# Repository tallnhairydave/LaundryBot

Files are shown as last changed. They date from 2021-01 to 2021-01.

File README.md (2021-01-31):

# LaundryBot
ESP8266 based CT Clamp sensor for monitoring washing machine power usage and reporting into HomeAssistant. Includes an OLED display for visible information in the kitchen, and is housed in a 3D printed enclosure. 

1. You need ESPHome add-on installed and running in HomeAssistant. 
1. You will need the fonts listed in fonts/readme.txt downloaded and installed in your HA installation in config/esphome/fonts/
1. Create a new ESPHome node
1. Update the laundrybot.yaml to suit your OTA and API passwords set during creation of the new node, and your WIFI network settings.
1. Compile and upload the code to your D1 Mini via serial for the first time from ESPHome. Future updates can then be OTA.
1. Add the code in the configuration.yaml file here on Github to your configuration.yaml - this will create the switch to turn on and off the display on the Laundrybot.
1. Check your configuration.yaml is valid, then restart HA.
1. Create a new entities card on your lovelace dashboard for Laundrybot. See lovelacecardcode.txt for my code for a basic status card. You can of course use Sensor cards if you want a nice graph of A or W usage over time for your washing machine.

Once you've got the data coming into HA, you can then fire off notifications etc depending on the washing machine state. :)

You'll also need a 3D printer to print out the enclosure :) I've included the STL's to print out my housing for the circuit board that holds the Wemos D1 mini, the display, and the circuit to connect to the CT Clamp.

**THIS IS DESIGNED AND BUILT TO WORK WITH A UK SINGLE PHASE 240V 3 CORE MAINS POWER CABLE, the CT Clamp goes around the LIVE core of the wire inside a junction box.**

I am using it to monitor my washing machine, so I've made an "extension lead" by cutting a 1 gang 5M extension cable in half, exposing the three cores and re-terminating them inside a junction box with screw down cable glands for cable entry. That way, the mains cable is safe and the CT clamp can be placed around the LIVE wire to enable current to be monitored. The washing machine then plugs into that "extension lead" instead of directly into the wall, and it goes without saying that **the extension lead has the same rating fuse installed in it's plug as the washing machine has in it's plug.**

Note, I've found that after laundrybot boots, it takes a few seconds once it's started sending data into HA before it "settles down" and stops reporting spurious current readings. 

**I AM IN NO WAY RESPONSIBLE FOR ANY ISSUES THAT MAY ARISE IF YOU BUILD THIS CIRCUIT AND WIRE UP ANYTHING TO IT. PROCEED AT YOUR OWN RISK**

## BILL OF MATERIALS:
* 1 x Wemos D1 Mini ESP8266 
* 1 x 1.3inch I2C Serial 128x64 SSH1106 OLED LCD Display  
* 1 x 4 pin female header for solderable protoboard for the display
* 2 x 8 pin female header for solderable protoboard for the D1 Mini (my board came with these)
* 2 x 8 pin male headers for the D1 mini (my board came with these and I just had to solder them on)
* 1 x SCT-013-030, 30A 0-1V output CT Clamp, e.g. https://www.amazon.co.uk/gp/product/B07MY361ZW - Important note, your CT clamp MUST have an inbuilt "burden resistor" as my circuit used (see the fritzing diagram) does include one, as the CT Clamp I used has a burden resistor built in. When I cut off the 3.5mm headphone jack from my CT Clamp, I found it had one red core and one black core. I connected these to the 2 wire terminal block as shown in the fritzing diagram. Make sure that you clamp it on the LIVE core inside the junction box with the ARROWS on the CT Clamp matching the direction of current flow. **NEVER ALLOW THE CT CLAMP TO OPERATE "OPEN CIRCUIT" i.e. do not connect it around the live wire and turn on the power, UNLESS the wires from the CT Clamp are connected to the terminals on the circuit board**
* 1 x Electrocookie 1/2 size solderable breadboard, or Adafruit 1/2 size protoboard. Both will fit in the case as they have the same 3mm fixing holes.
* 1 x 90 degree micro USB cable (if you want the power for the D1 mini to exit downwards from the case)
* 2 x M3x6 (no longer than M3x8) machine screws to hold the protoboard in the case
* 1 x 10µF Capacitor
* 2 x 10k Resistors - according to this guide at https://savjee.be/2019/07/Home-Energy-Monitor-ESP32-CT-Sensor-Emonlib/ (Thanks dude, your article on how to wire up the CT Clamp was invaluable!) any resistors between 10K and 470K are suitable, as long as they are both the same value.
* 1 x 2 wires screw terminal for solderable protoboard (note that the terminal block I used occupies 3 pins width on the board, with an unused column between it's two pins, see the fritzing diagram)
* 2 x M2.5x8 machine screws to hold the display to it's printed support. I designed the support to have M3 screw holes, but they printed too small so had to use M2.5 screws instead. YMMV
* A length of CAT6 network cable to run from the laundrybot location to the location of your power enclosure to house the CT Clamp. I used CAT6 as I had some lying around. CAT5e will work fine.  You could simply cut the ends off of a suitable length ethernet cable and use that instead of using spare cable from a spool like I did. 
* A small piece of 1mm thick foam tape (e.g. 3M VHB) to stick the base of the screen support piece to the protoboard if desired.
* Assorted 22 AWG wires to make jumpers for the solderable protoboard
* Assorted heatshrink tube (a) to tidy the wiring loom for the display, (b) to insulate the soldered joint between the CT Clamp to two pairs of the CAT6 cable used to extend the wiring, and (c) as needed for the mains cable, depending on how you terminate it inside the junction box.
* 1 x zip tie to act as strain relief on the CAT6 cable where it enters the Laundrybot housing in case it somehow gets tugged. You can also hot-glue it down to the protoboard. 
* 1 x ABS junction box at large enough to house the CT clamp and the mains power cable. Mine was 15cm x 11cm x 7cm and was just about the right size.
* 1 x one-gang extension lead that is long enough to go from the washer's mains socket to the floor, and tuck under the cabinet next to the washer. I ended up using a 5m cable.
* 1 x cable termination method of your choice to join the mains cable back together inside the junction box
* 3 x cable glands for the junction box (i used 20mm screw down cable glands that I had spare).
* 2 x 3M Command Strips (or other tape of your choice) to fix the Laundrybot enclosure to the wall.

**NOTE 31 Jan 2021 - when all connected up and with no load, I see values between 0.03A and 0.05A getting reported back to home assistant. i have yet worked out a solution for this.**

## Wiring diagram for the protoboard
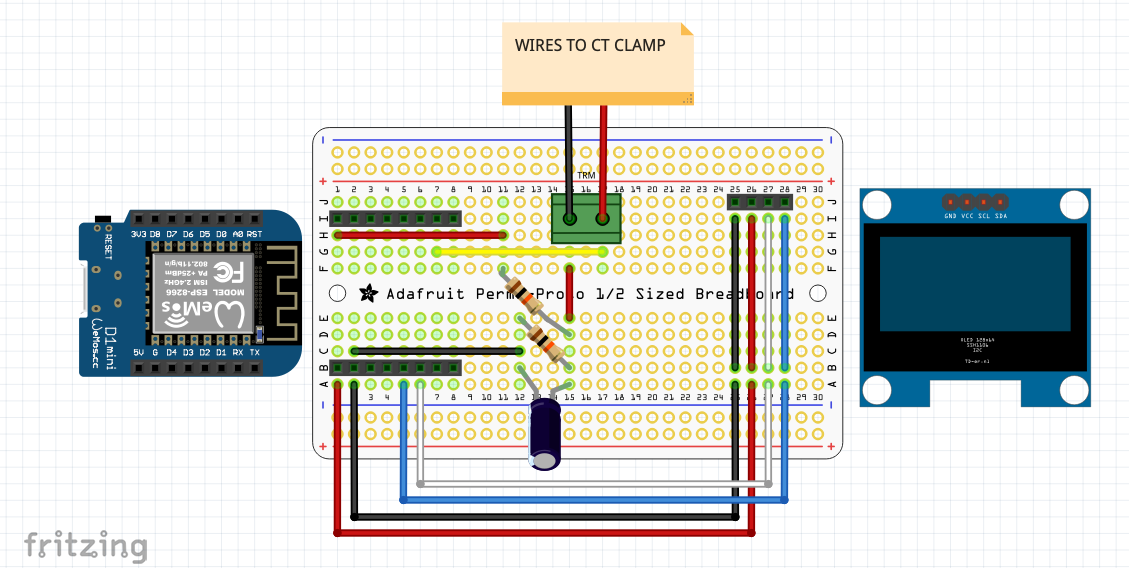
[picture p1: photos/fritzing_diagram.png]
wiring diagram


## Photos:
**Circuit assembled on protoboard and installed in case.** 
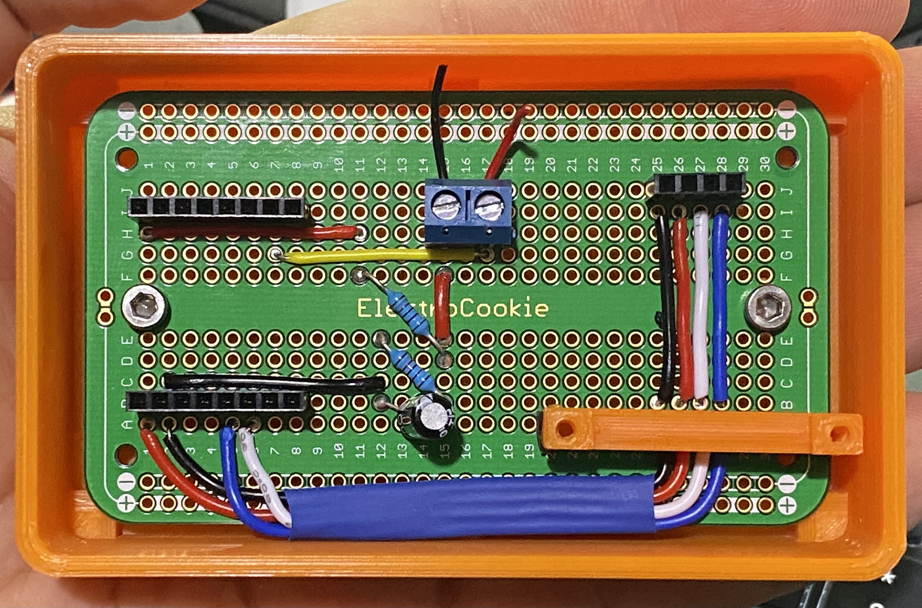
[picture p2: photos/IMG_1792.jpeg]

Note the 3D printed support "bridge" for the screen attached to the protoboard with tape.

**Circuit in case with D1 Mini and display installed**
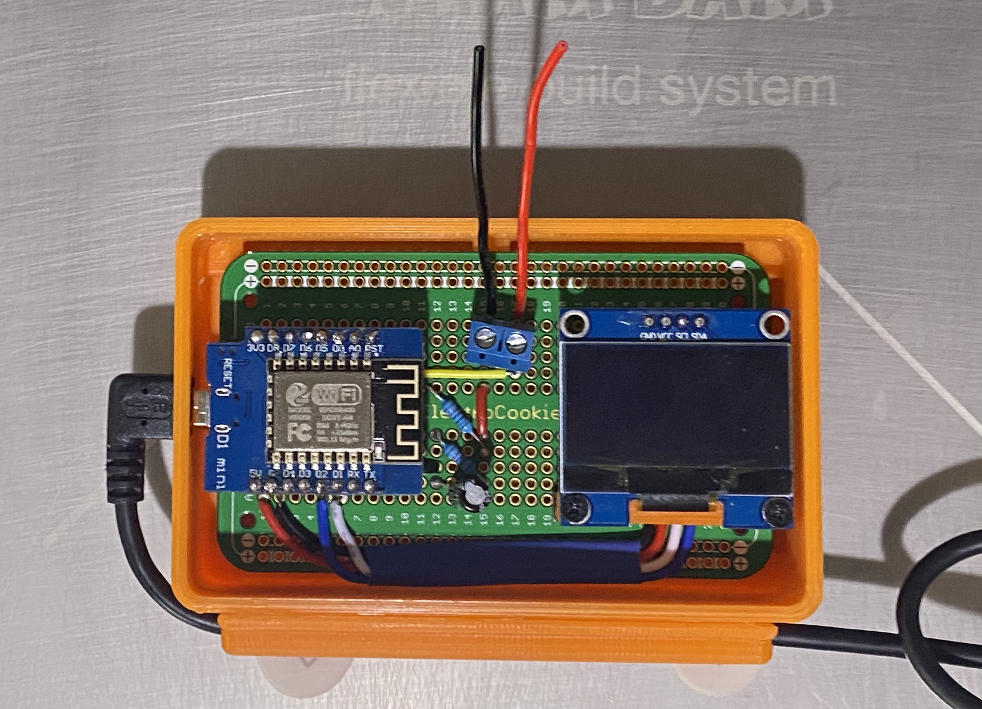
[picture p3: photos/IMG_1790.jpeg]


**3/4 view of the enclosure showing the 7.5mm hole for the CAT6 cable to enter the case, and the slot for the Micro USB power cable to the D1 Mini.**
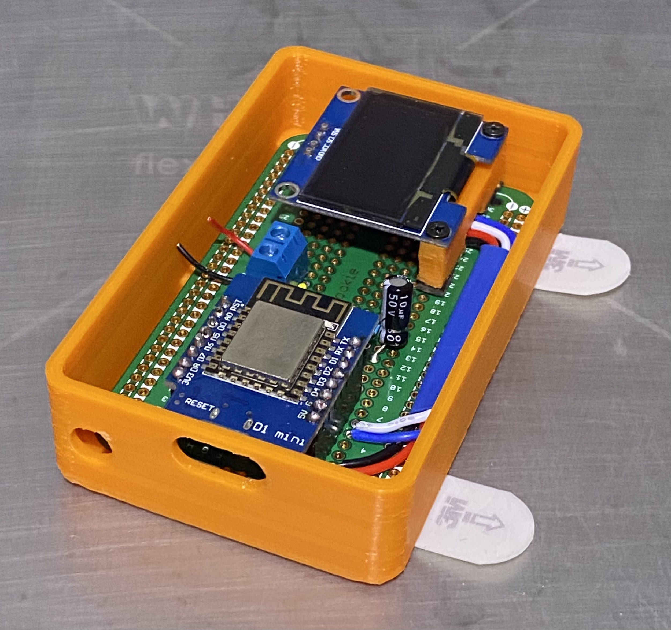
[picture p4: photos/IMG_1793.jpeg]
Case 3/4 view


**Assembled case, with USB cable, and attached cable tidy part.**
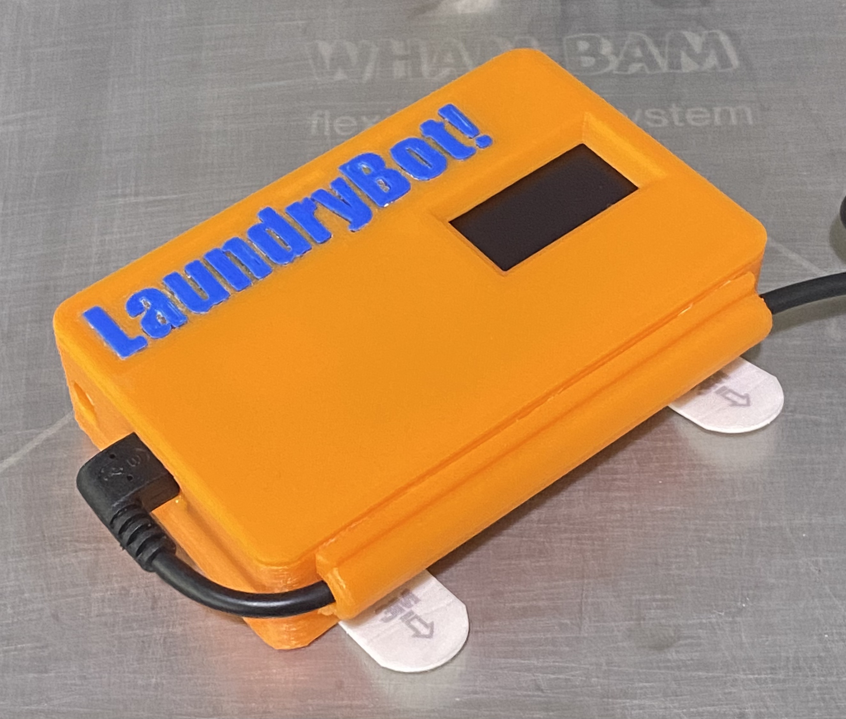
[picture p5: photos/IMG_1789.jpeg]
assembled case, ready to go on wall


**Inside the "Junction Box" I made so I could get the CT Clamp on the L wire**
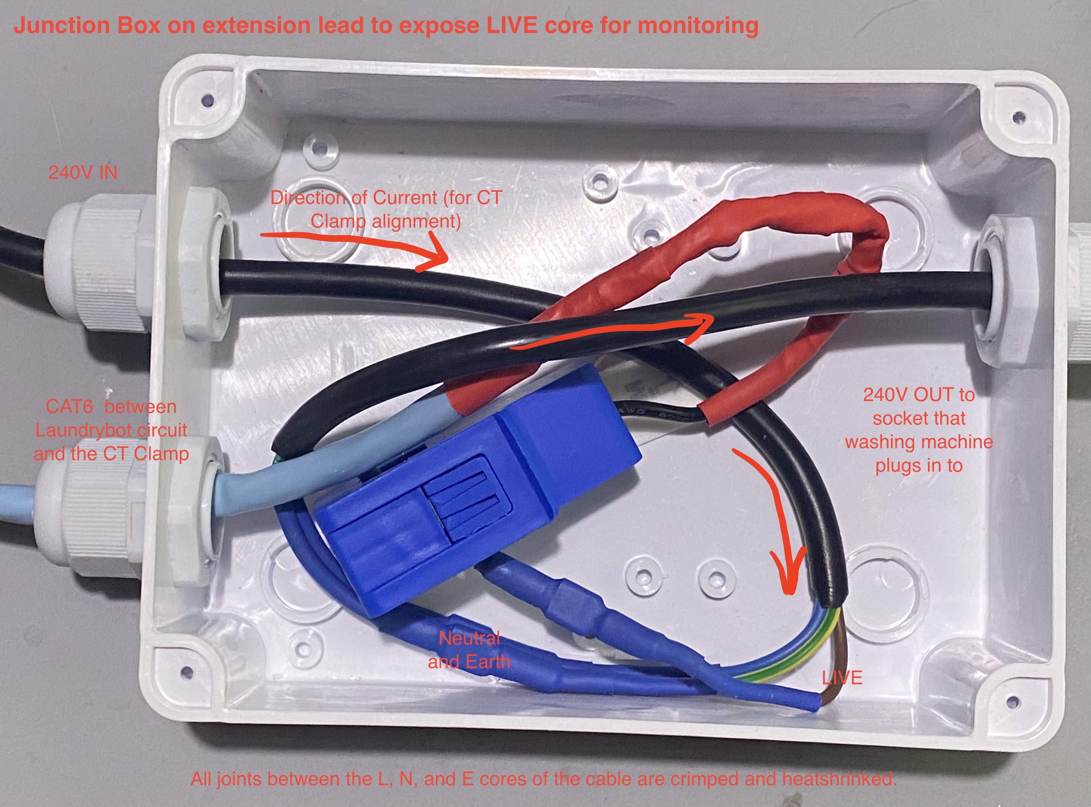
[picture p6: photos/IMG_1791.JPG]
Inside the junction box


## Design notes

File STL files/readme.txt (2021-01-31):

This folder contains the STL files for my housing. 

I've included three lid options 
- a blank lid
- a lid with the LaundryBot! name already in place, raised from the surface by 0.5mm
- a lid with the LaundryBot! name embossed into the surface

I've included the STLs for the letters in LaundryBot! so you can print them in a different colour and then glue them in place in the lid. 

Note that when I imported the "." of the "!" into Cura, it resized it to 1000%. Just resize it's width back to 2.402mm and it'll be fine. (it's 1.5mm tall)

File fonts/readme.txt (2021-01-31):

Font files need to be uploaded to config/esphome/fonts in your HA instance. 

I'm using:
arial.ttf (pulled from my PC),
materialdesignicons-webfont.ttf (freely available from https://materialdesignicons.com)
BebasNeue-Regular.ttf (free download from https://www.dafont.com/bebas-neue.font)

You'll need to grab these yourself, or change the fonts you're using in the laundrybot.yaml to suit your preferences

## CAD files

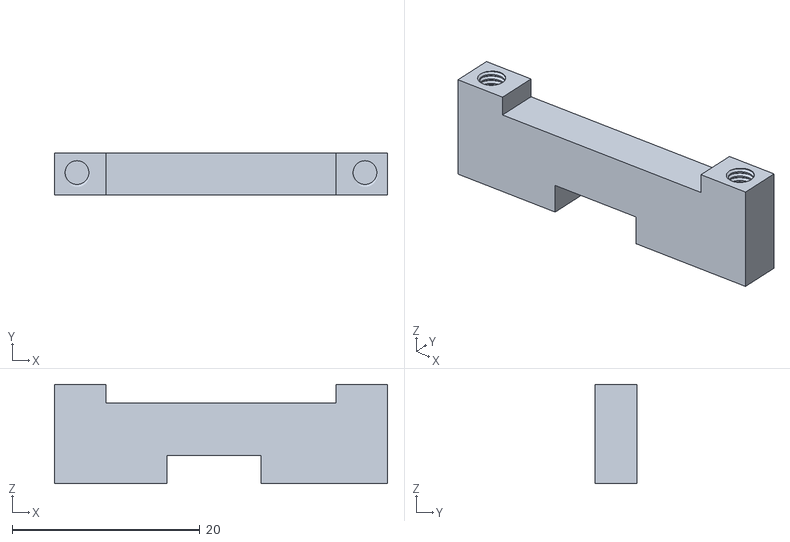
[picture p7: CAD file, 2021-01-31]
STL files/suppport_for_display.stl
35.5 x 4.50 x 10.6

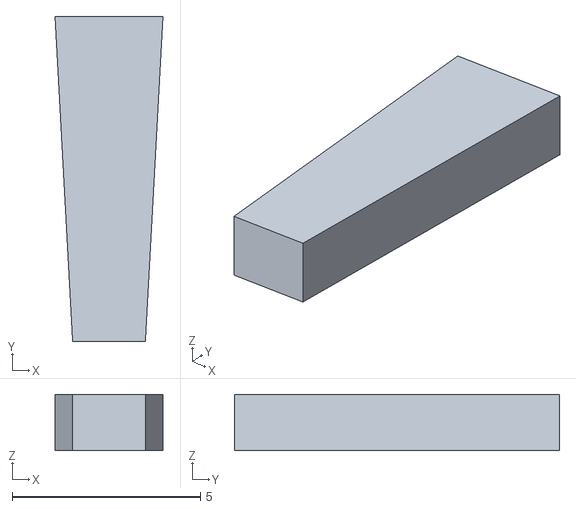
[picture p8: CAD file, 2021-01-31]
STL files/exclamation_mark_upper.stl
2.87 x 8.64 x 1.50

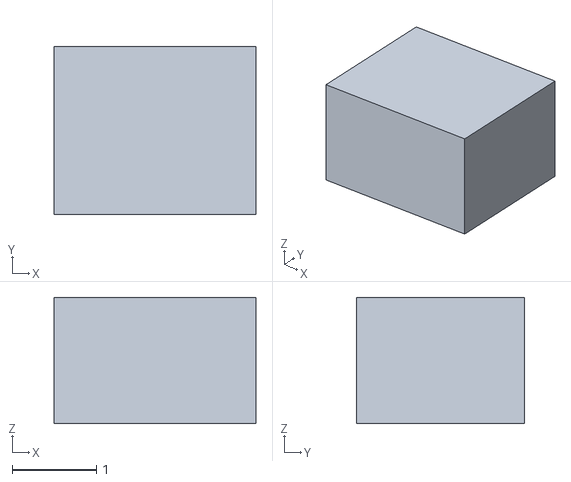
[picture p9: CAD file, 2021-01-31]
STL files/exclamation_mark_dot_2.4mm_wide.stl
2.40 x 2.00 x 1.50

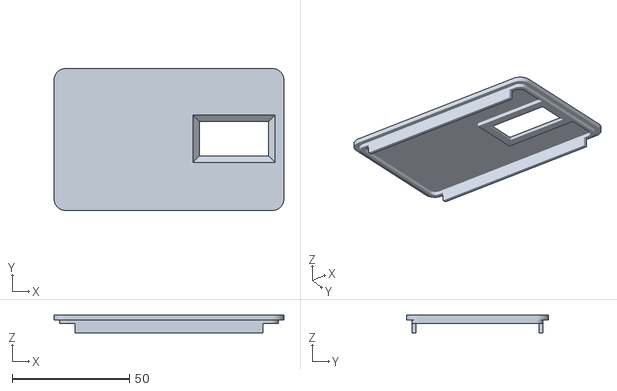
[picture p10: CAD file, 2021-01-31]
STL files/laundrybot_blank_lid.stl
98.0 x 60.5 x 7.50

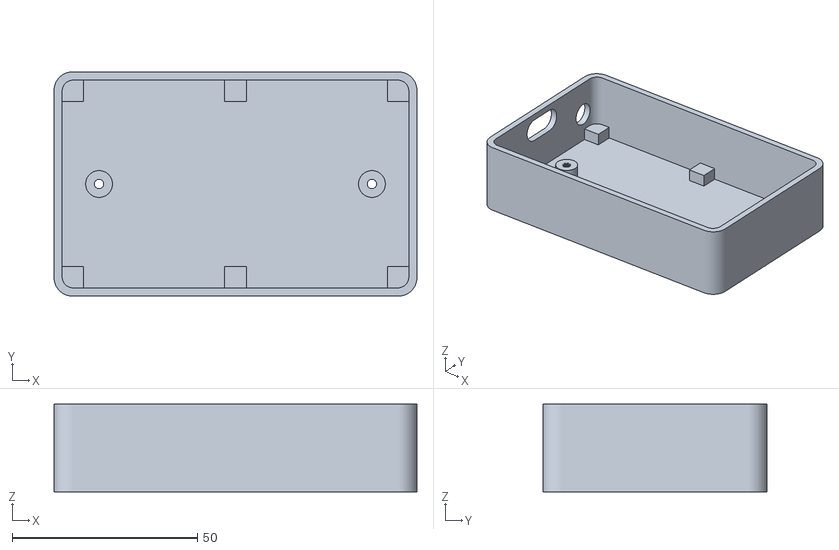
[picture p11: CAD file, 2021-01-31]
STL files/laundrybot_base.stl
98.0 x 60.5 x 23.7

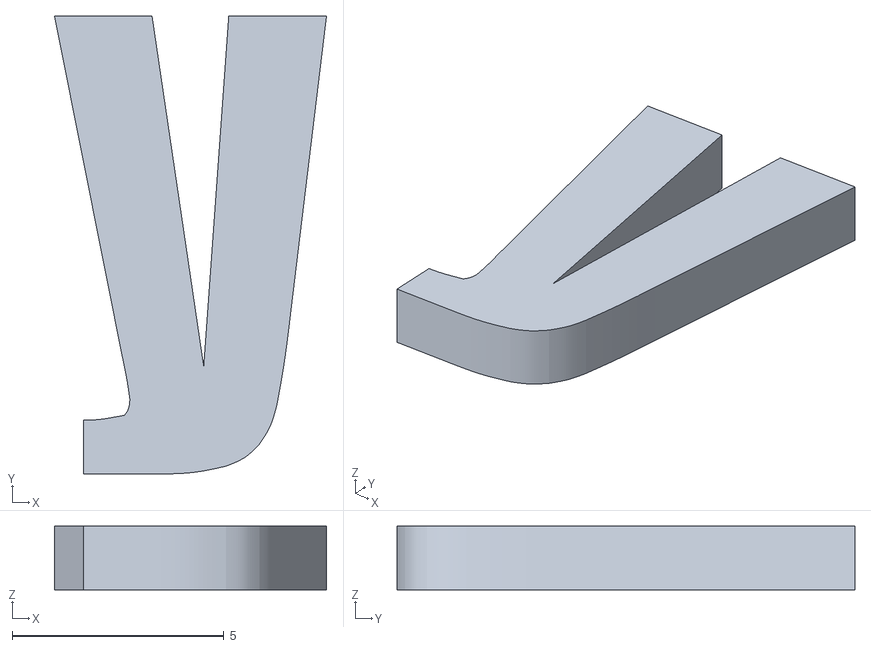
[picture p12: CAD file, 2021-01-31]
STL files/letter_y.stl
6.42 x 10.8 x 1.50

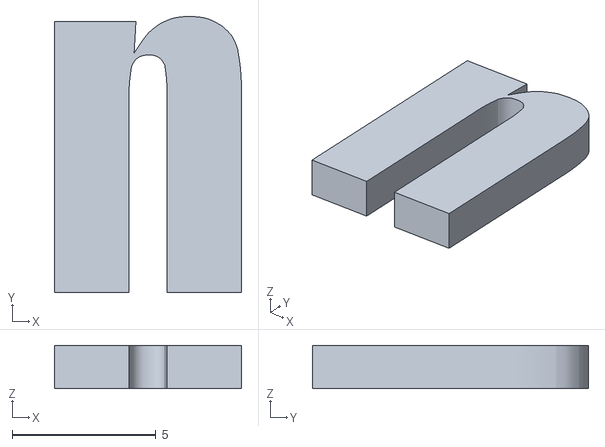
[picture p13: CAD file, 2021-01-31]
STL files/letter_n.stl
6.51 x 9.61 x 1.50

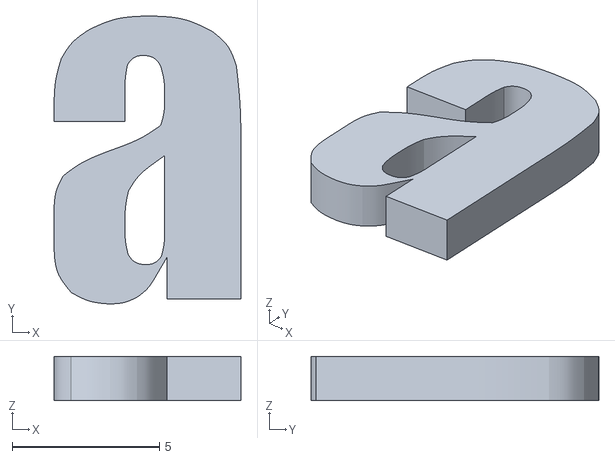
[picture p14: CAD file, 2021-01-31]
STL files/letter_a.stl
6.35 x 9.79 x 1.50

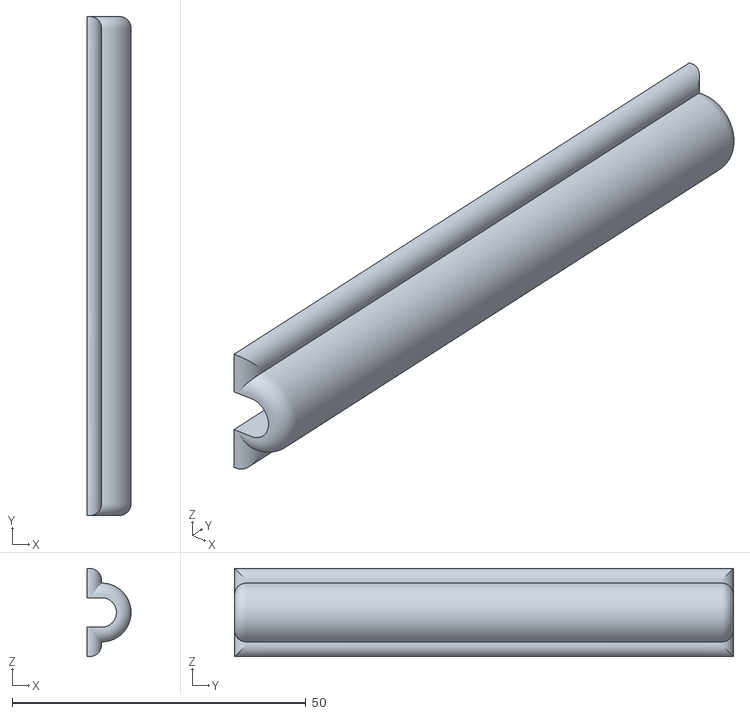
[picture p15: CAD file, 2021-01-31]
STL files/USB_cable_guide.stl
7.53 x 85.0 x 15.0

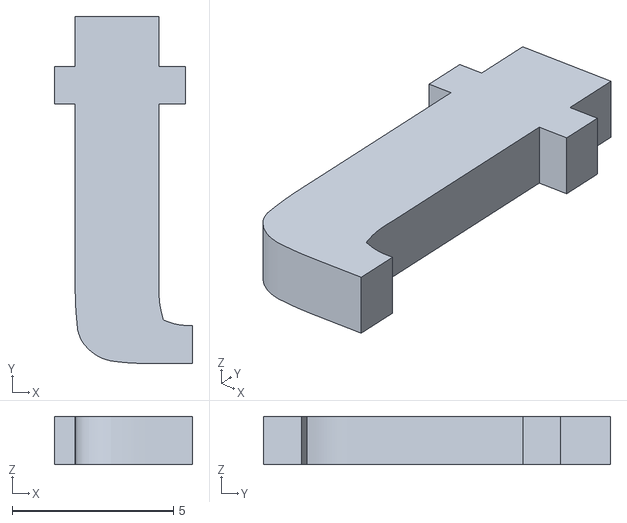
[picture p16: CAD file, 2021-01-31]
STL files/letter_t.stl
4.28 x 10.7 x 1.50

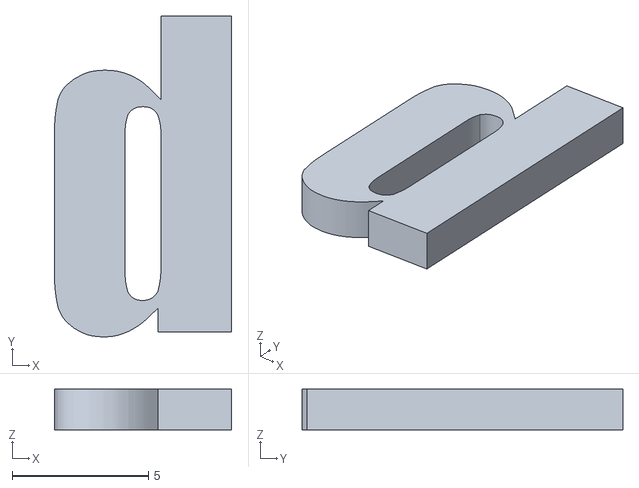
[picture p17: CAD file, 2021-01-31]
STL files/letter_d.stl
6.50 x 11.8 x 1.50

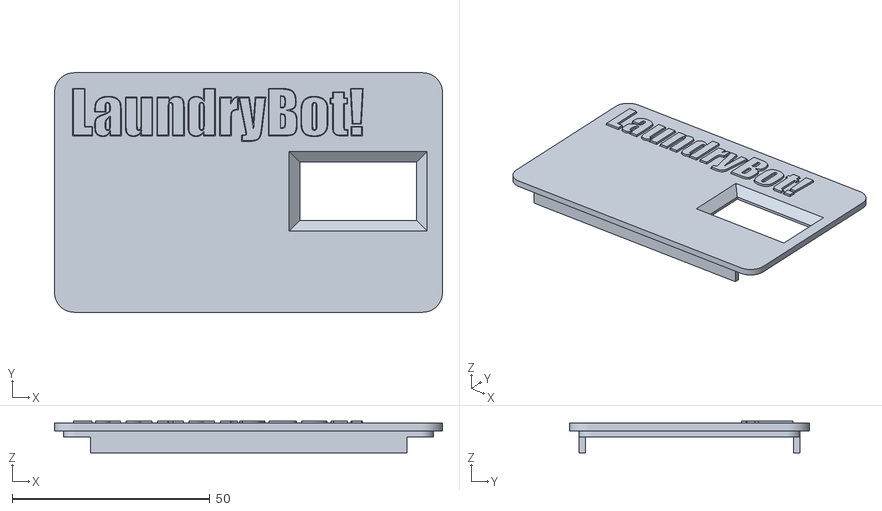
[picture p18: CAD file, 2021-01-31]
STL files/laundrybot_lid_with_raised_text.stl
98.0 x 60.5 x 8.00

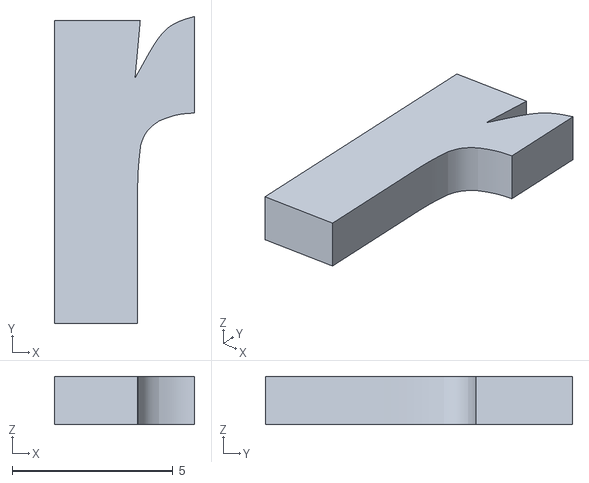
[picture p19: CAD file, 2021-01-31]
STL files/letter_r.stl
4.37 x 9.56 x 1.50

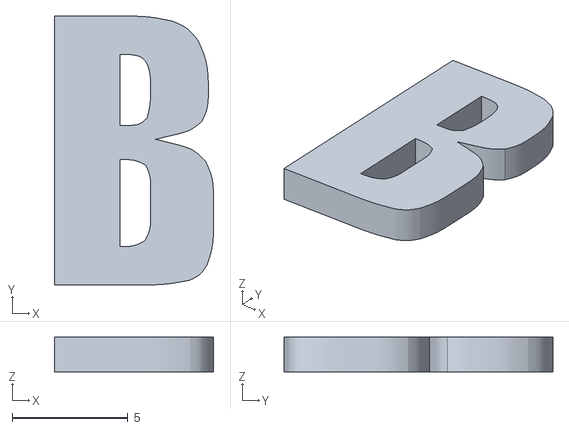
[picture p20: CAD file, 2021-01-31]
STL files/letter_b.stl
6.86 x 11.6 x 1.50

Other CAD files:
STL files/letter_u.stl
STL files/laundrybot_lid_with_inset_text.stl
STL files/letter_l.stl
STL files/letter_o.stl

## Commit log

2021-01-31 Add files via upload
    forgot to include this in the original commit.
    [suppport_for_display.stl]
2021-01-31 Add files via upload
    Wiring diagram for the project created with Fritzing.
2021-01-31 Add files via upload
    Fritzing diagram for the wiring of the circuit
2021-01-31 Update laundrybot.yaml
    Due to noise in the circuit, it always reports a spurious amperage of between 0.04A and 0.08A even when power to the washer is OFF. (It should theoretically report OA in that case)
    So I’ve set the circuit to report the washer is idle for anything less than a reported 20W power “usage” in order to filter out sténose spurious readings.
